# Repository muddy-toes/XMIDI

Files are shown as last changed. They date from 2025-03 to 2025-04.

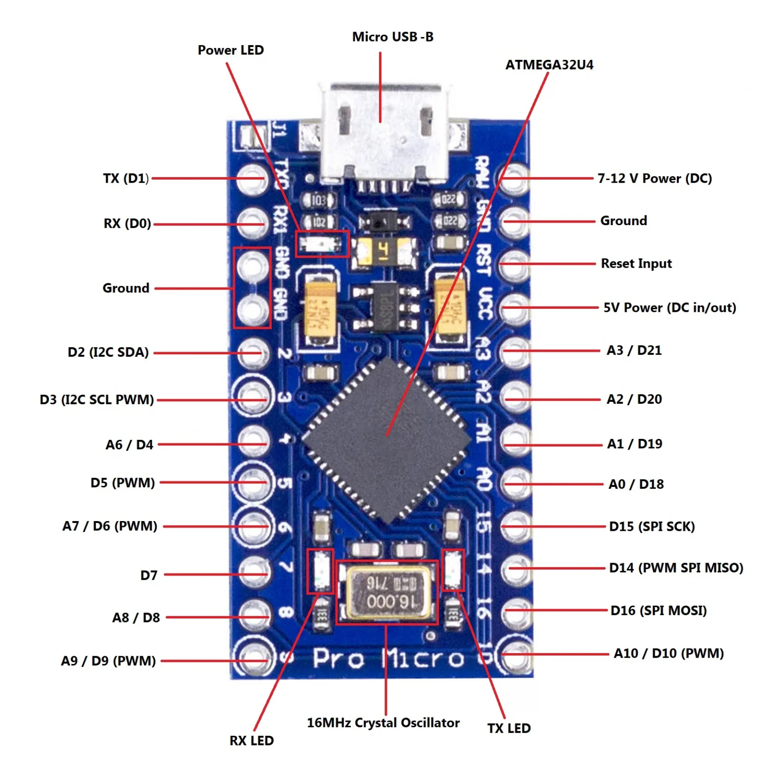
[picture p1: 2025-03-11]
doc/Arduino-Pro-Micro-Pinout-Diagram-Gadget-AU-1536x1536.webp

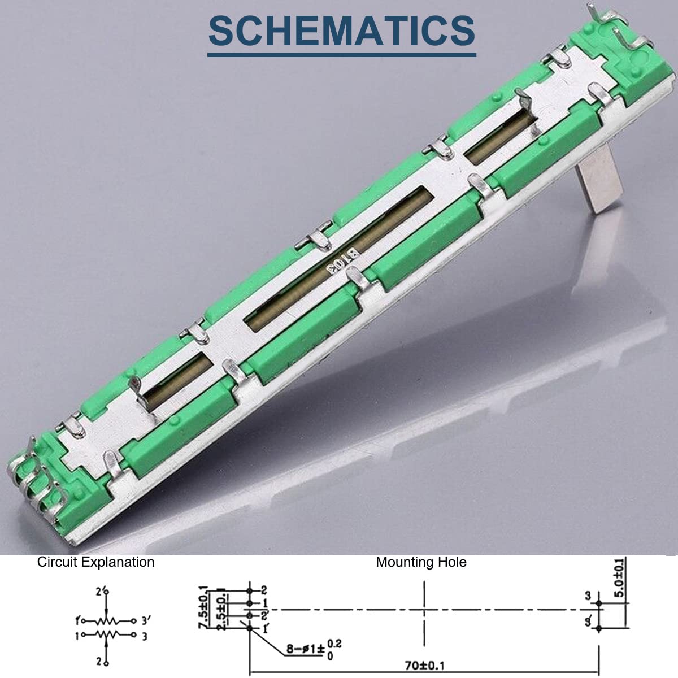
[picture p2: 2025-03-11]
doc/sliderpotwiring.jpg

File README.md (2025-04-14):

midi-over-usb control box to interface with xtoys for controlling an ossm running the xtoys v2 firmware

Pics in doc/

The buttons on the box, as pictured in doc/as-built.jpg:

  - The left green is speed mode, the right is position mode.
  - The yellow is pause/unpause
  - The red is full stop
  - The encoder is speed in speed mode
  - The left slider is depth
  - The right slider is stroke
  - The blue is to set minimum depth
  - The black resets minimum depth back to zero

Full stroke is left all the way down and right all the way up.

Left at the bottom and right halfway will be a half stroke.  If you then push
left up 20%, you'll have a stroke from 20-70.

If you then push the blue button, it'll set that to the minimum, which makes
the current slider position 20% up from where it currently is and it will ramp
to its new increased position, so if you want to set the minimum and keep it
there, hit blue and then drop the slider to zero.  The black button reset will
also ramp the low to adjust.

# Caution:

**Build this and use it at your own risk.**

Connect it and play with it while there isn't a living being on the business
end of the machine, yourself included.

Always be able to move away from the machine or to quickly cut its power!

# Xtoys:

The xtoys script is in xtoys/.  See its README for details.  I did not create Xtoys nor
do I have any affiliation with them.

# Components:

  - Arduino Pro Micro 5V
  - 6x 12mm momentary push buttons
  - 1x rotary encoder
  - 2x 75mm slider potentiometers, B10K, B103

Component reference info in doc/

# Parts:

STL files are in the printables/ directory

# Wiring notes:

  - Button - speed mode - pin 2 - key 36
  - Button - position mode - pin 3 - key 37
  - Button - Pause - pin 4 - key 38
  - Button - Stop/retract - pin 5 - key 39

  - Button - set min - pin 6 - key 40
  - Button - zero min - pin 7 - key 41

  - Encoder - Speed - pins 14 & 15

  - Slider - Stroke min - pin A9
  - Slider - Stroke range - pin A8

All components buttons are connected between the given pin and gnd

The sliders are 10k B pots between gnd and 5V

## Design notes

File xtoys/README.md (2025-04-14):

This is the source to my XToys script for this control.  It's not published because mine is the only one of these
currently.  If you build one and want to use it, let me know and I'll just publish the script on XToys.

To set it up in xtoys:

  - Open the menu (three lines)
  - Select Scripts under Manage Your Data
  - Click the + in the bottom corner
  - Click the three dots in the top bar
  - Select Import/Export
  - Replace the contents of the editor with the xtoys-script.json file from this directory (copy/paste)
  - Click Save
  - Give it a name and Save it

  - Open the menu (three lines)
  - Select Dashboard Mode
  - Click the + in the top bar to add a block
  - Select Tools
  - Select MIDI
  - Select the script you just created

  - If your OSSM or other speed/position stroker block isn't already added, add it.
  - Click the plug icon in the MIDI block to connect it to your stroker.
  - Plug in your controller
  - Click the gray button in the MIDI block to enable it and select your device from the dropdown that
    appears.

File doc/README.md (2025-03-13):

The slider wiring diagram is top-down.  If the slider isn't responding properly, check that pins 1 & 2 or 1' and 2' aren't swapped in your wiring.

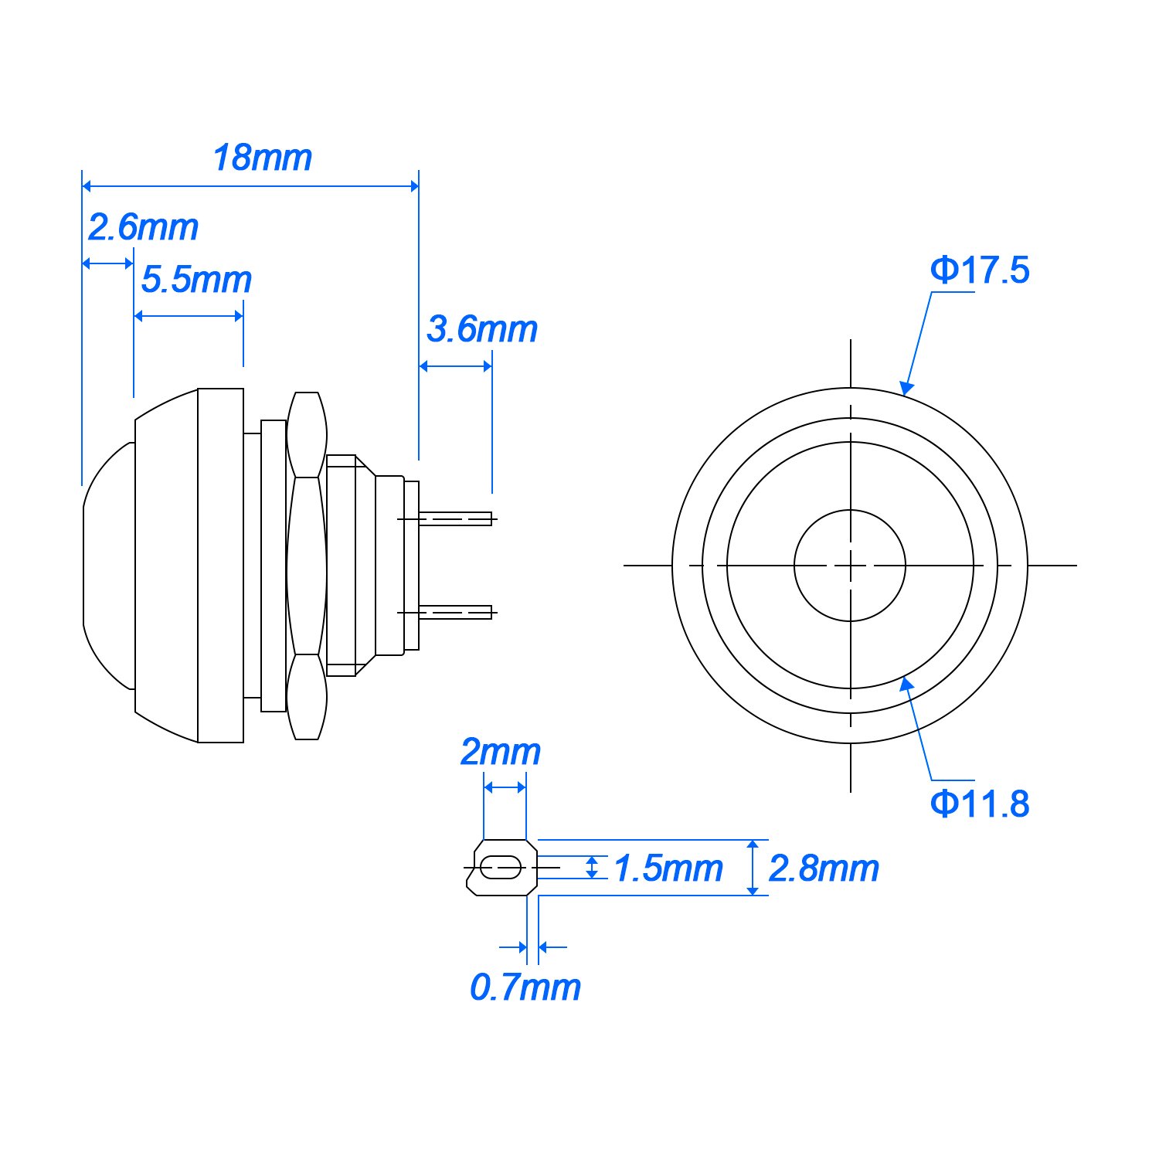
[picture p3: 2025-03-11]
doc/12mmbutton.jpg

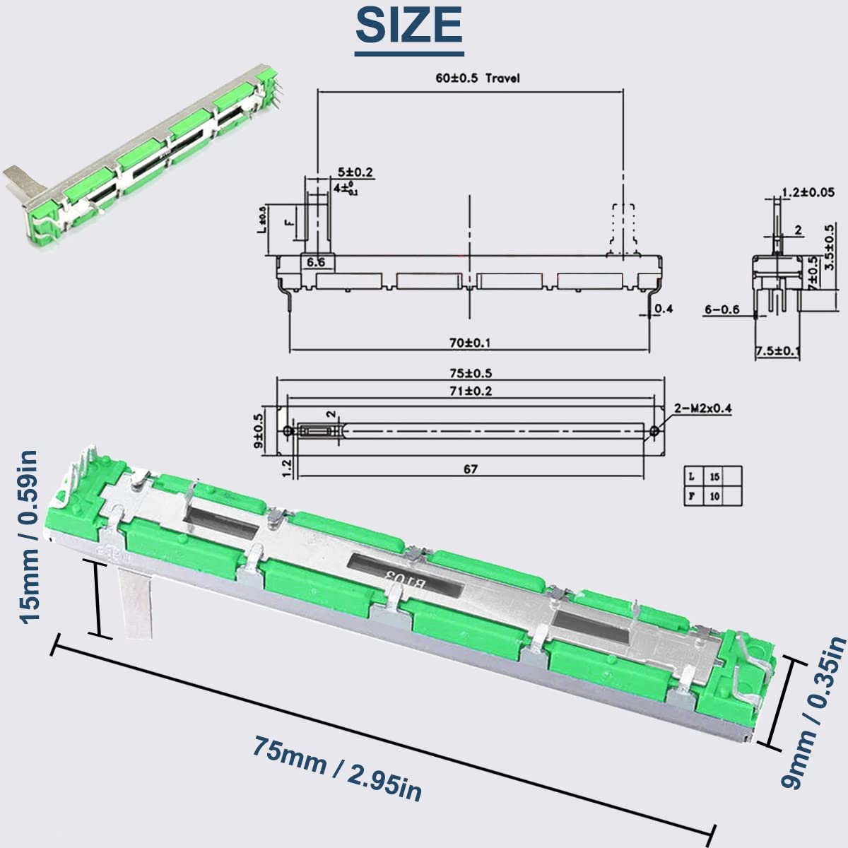
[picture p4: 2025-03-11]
doc/sliderpot.jpg

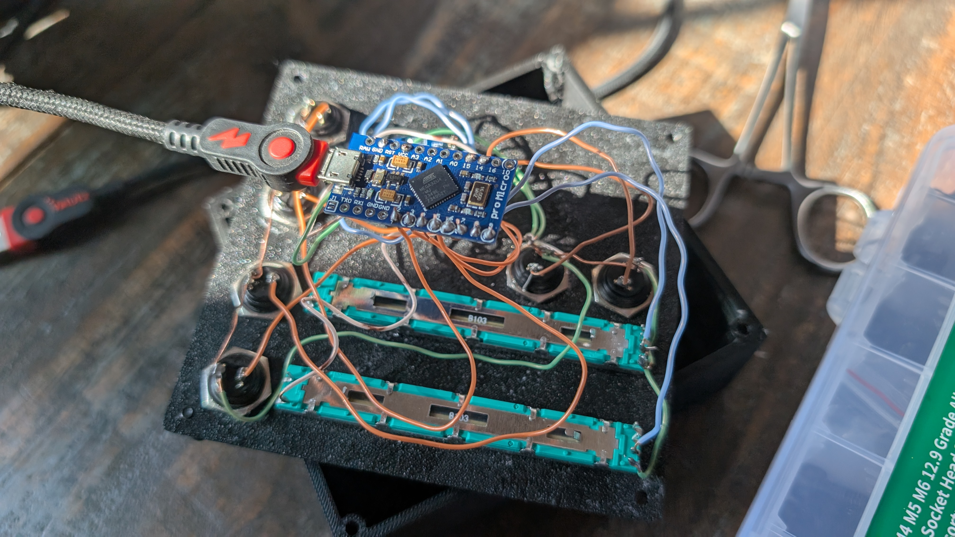
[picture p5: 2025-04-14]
doc/as-wired.jpg

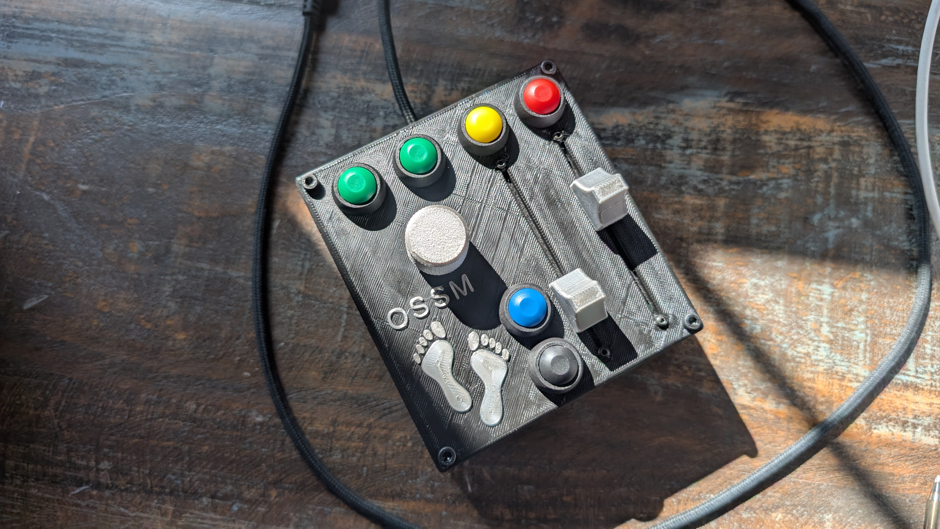
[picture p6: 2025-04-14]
doc/as-built.jpg

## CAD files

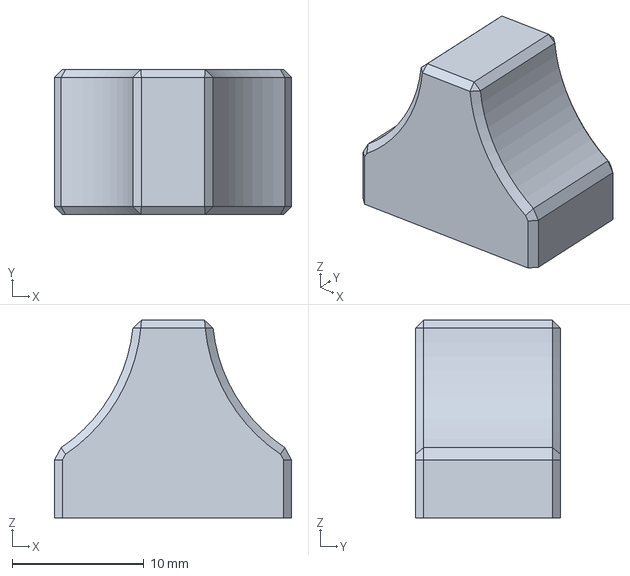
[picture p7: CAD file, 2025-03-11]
printables/sliderbutton.FCStd
18.0 x 11.0 x 15.0 mm

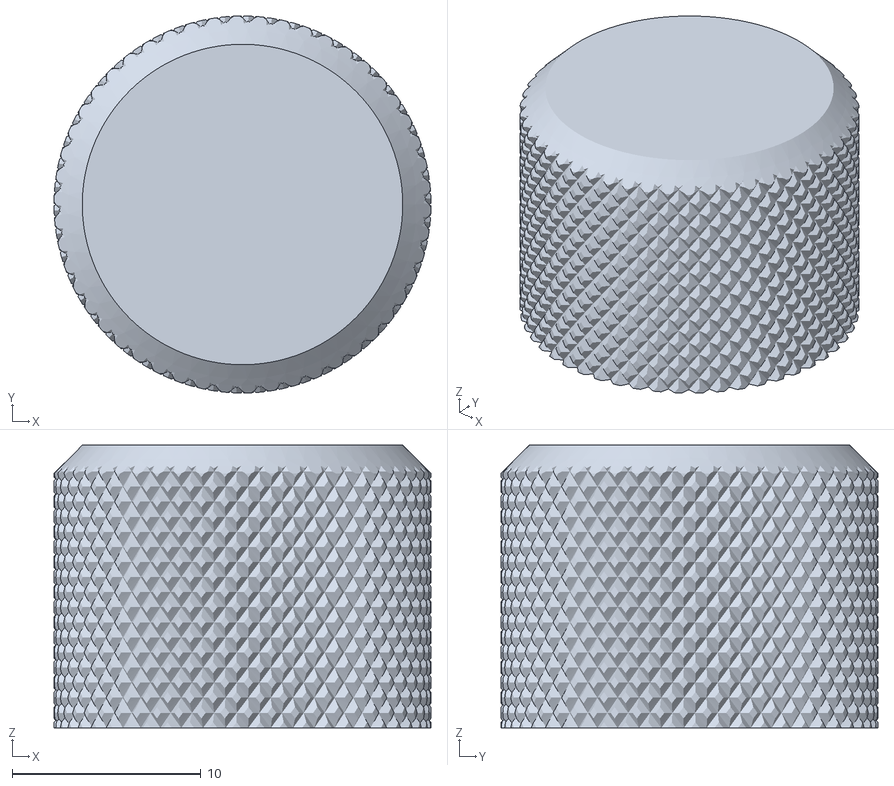
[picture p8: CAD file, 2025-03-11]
printables/knurled-knob-Part.stl
20.0 x 20.0 x 15.0

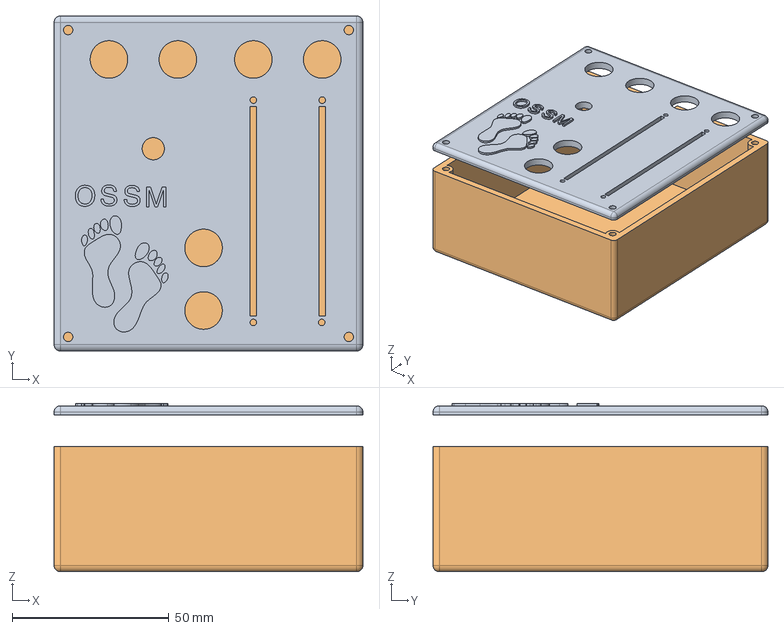
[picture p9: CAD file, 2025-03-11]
printables/midi-panel-layout.FCStd
98.7 x 107.0 x 53.8 mm
panel

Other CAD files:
printables/knurled-knob.FCStd
printables/sliderbutton-Part.stl

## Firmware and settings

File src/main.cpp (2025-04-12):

/*
  Based on Sketch built by Gustavo Silveira (aka Music Nerd)
  Modified by Dolce Wang
  Modified by muddytoes

  This code is only for Arduinos that use ATmega32u4 (like Micro, Pro Micro, Leonardo...)
*/
#include <Arduino.h>
#include "MIDIUSB.h"

// Buttons
const int NButtons = 6; //***  total number of buttons
const int buttonPin[NButtons] = {2, 3, 4, 5, 6, 7}; //*** define Digital Pins connected from Buttons to Arduino; (ie {10, 16, 14, 15, 6, 7, 8, 9, 2, 3, 4, 5}; 12 buttons)
int buttonCState[NButtons] = {};        // stores the button current value
int buttonPState[NButtons] = {};        // stores the button previous value
unsigned long lastDebounceTime[NButtons] = {0};  // the last time the output pin was toggled
unsigned long debounceDelay = 50;    //** the debounce time; increase if the output flickers

// Pots
//const int NPots = 7; //*** total number of pots (knobs and faders)
//const int potPin[NPots] = {A9, A8, A7, A6, A3, A2, A1}; //*** define Analog Pins connected from Pots to Arduino; Leave nothing in the array if 0 pots {}
const int NPots = 2; //*** total number of pots (knobs and faders)
const int potPin[NPots] = {A9, A8}; //*** define Analog Pins connected from Pots to Arduino; Leave nothing in the array if 0 pots {}
const int potMin[NPots] = {0, 10};
const int potMax[NPots] = {90, 100};
int potCState[NPots] = {0}; // Current state of the pot; delete 0 if 0 pots
int potPState[NPots] = {0}; // Previous state of the pot; delete 0 if 0 pots
int potVar = 0; // Difference between the current and previous state of the pot
int midiCState[NPots] = {0}; // Current state of the midi value; delete 0 if 0 pots
int midiPState[NPots] = {0}; // Previous state of the midi value; delete 0 if 0 pots
const int TIMEOUT = 300; //* Amount of time the potentiometer will be read after it exceeds the varThreshold
const int varThreshold = 10; //* Threshold for the potentiometer signal variation
boolean potMoving = true; // If the potentiometer is moving
unsigned long PTime[NPots] = {0}; // Previously stored time; delete 0 if 0 pots
unsigned long timer[NPots] = {0}; // Stores the time that has elapsed since the timer was reset; delete 0 if 0 pots

// Encoder
const int NEncoders = 1;
const int encoderPinA[NEncoders] = {15};
const int encoderPinB[NEncoders] = {14};
int encoderPState[NEncoders] = {0};
int encoderCState[NEncoders] = {0};
int encoderVal[NEncoders] = {0};

// MIDI Assignments 
byte midiCh = 1; //* MIDI channel to be used
byte note = 36; //* Lowest note to be used; 36 = C2; 60 = Middle C
byte cc = 1; //* Lowest MIDI CC to be used
byte encoderBaseOffset = 10;

void noteOn(byte channel, byte pitch, byte velocity) {
  midiEventPacket_t noteOn = {0x09, (byte)(0x90 | channel), pitch, velocity};
  MidiUSB.sendMIDI(noteOn);
  MidiUSB.flush();
}

void noteOff(byte channel, byte pitch, byte velocity) {
  midiEventPacket_t noteOff = {0x08, (byte)(0x80 | channel), pitch, velocity};
  MidiUSB.sendMIDI(noteOff);
  MidiUSB.flush();
}

void controlChange(byte channel, byte control, byte value) {
  midiEventPacket_t event = {0x0B, (byte)(0xB0 | channel), control, value};
  MidiUSB.sendMIDI(event);
  MidiUSB.flush();
}

void setup() {
  Serial.begin(31250); // MIDI baud rate 31250

  for( int i = 0; i < NButtons; i++ ) {
    pinMode(buttonPin[i], INPUT_PULLUP);
  }
}

void loop() {

  // Buttons
  for( byte i = 0; i < NButtons; i++ ) {
    buttonCState[i] = digitalRead(buttonPin[i]);  // read pins from arduino

    if( (millis() - lastDebounceTime[i]) > debounceDelay ) {
      if( buttonPState[i] != buttonCState[i] ) {
        lastDebounceTime[i] = millis();

        if( buttonCState[i] == LOW ) {
          noteOn(midiCh, note + i, 127);  // channel, note, velocity

          // custom.  If speed mode button or stop button, reset speed to 0
          if( i == 0 || i == 3 ) {
              encoderVal[0] = 0;
          }

        } else {
          noteOff(midiCh, note + i, 0);  // channel, note, velocity
        }

        buttonPState[i] = buttonCState[i];
      }
    }
  }

  // Encoders
  for( byte i = 0; i < NEncoders; i++ ) {
    encoderCState[i] = digitalRead(encoderPinA[i]);
    if( encoderCState[i] != encoderPState[i] ) {
      if( digitalRead(encoderPinB[i]) != encoderCState[i] )
        encoderVal[i]--;
      else
        encoderVal[i]++;

      if( encoderVal[i] > 100)
        encoderVal[i] = 100;
      else if( encoderVal[i] < 0 )
        encoderVal[i] = 0;

      controlChange(midiCh, encoderBaseOffset + cc + i, encoderVal[i] < 3 ? 0 : encoderVal[i]);

    encoderPState[i] = encoderCState[i];
    }
  }

  // Pots
  for( byte i = 0; i < NPots; i++ ) {
    potCState[i] = analogRead(potPin[i]);
    midiCState[i] = map(potCState[i], 0, 1023, potMin[i], potMax[i]); // Maps the reading of the potCState to a value usable in midi
    potVar = abs(potCState[i] - potPState[i]); // Calculates the absolute value between the difference between the current and previous state of the pot

    if( potVar > varThreshold ) { // Opens the gate if the potentiometer variation is greater than the threshold
      PTime[i] = millis(); // Stores the previous time
    }

    timer[i] = millis() - PTime[i]; // Resets the timer 11000 - 11000 = 0ms

    if( timer[i] < TIMEOUT ) // If the timer is less than the maximum allowed time it means that the potentiometer is still moving
      potMoving = true;
    else
      potMoving = false;

    if( potMoving == true ) { // If the potentiometer is still moving, send the change control
      if( midiPState[i] != midiCState[i] ) {
        controlChange(midiCh, cc + i, midiCState[i]); //  (channel, CC number,  CC value)
        potPState[i] = potCState[i]; // Stores the current reading of the potentiometer to compare with the next
        midiPState[i] = midiCState[i];
      }
    }
  }

}

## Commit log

2025-03-11 Initial commit
    midi-over-usb control box to interface with xtoys for controlling an
    ossm running the xtoys v2 firmware
    [midi-panel-layout-Body001.stl, midi-panel-layout-Partpanel.stl, midi-panel-layout.FCStd]
2025-03-11 Update readme, add other printables
    Printables includes the top panel, case body, encoder knob (speed) and
    slider buttons (min depth & range)
    [knurled-knob-Part.stl, knurled-knob.FCStd, sliderbutton-Part.stl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]
2025-04-12 correct warnings, add notes
    [main.cpp]
